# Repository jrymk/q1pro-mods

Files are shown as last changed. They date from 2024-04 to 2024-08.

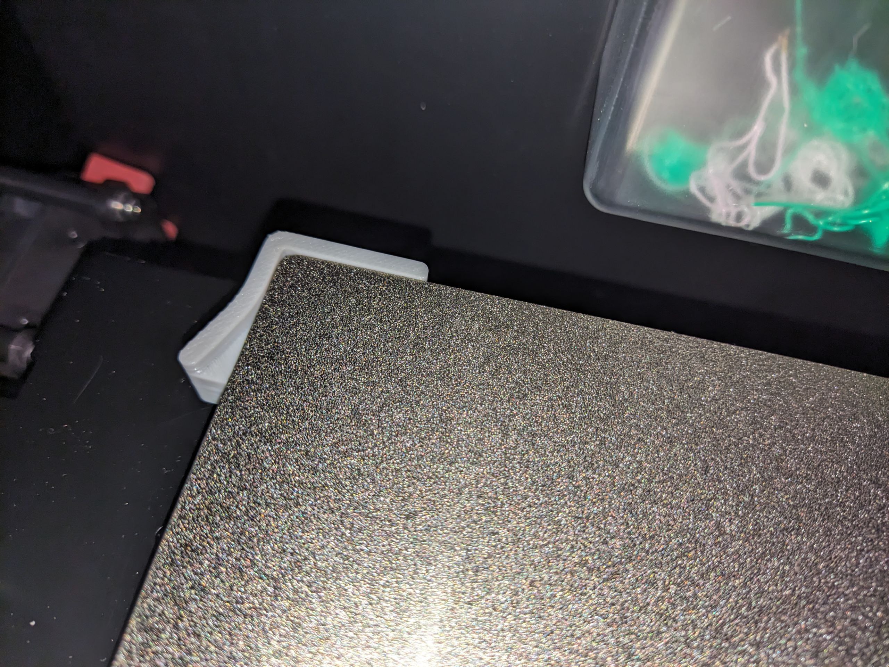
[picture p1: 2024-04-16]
Build Plate Guide/MakerWorld/photo_1_2024-04-17_00-07-08.jpg

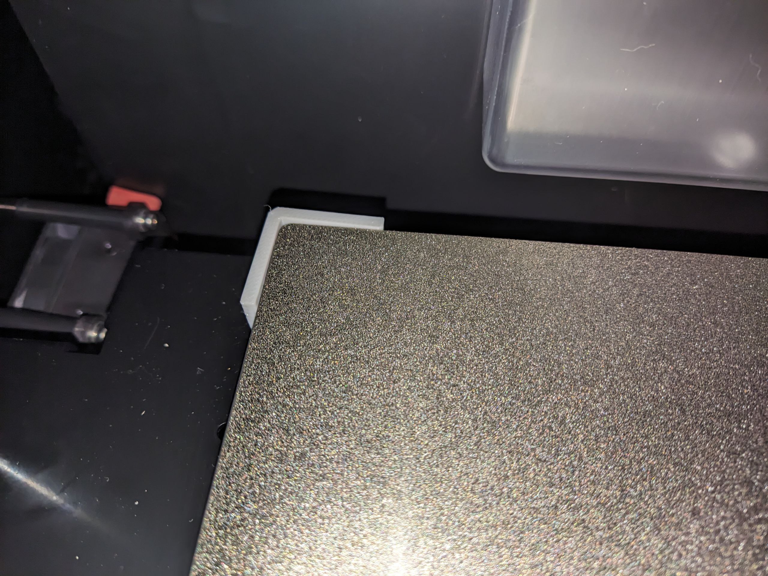
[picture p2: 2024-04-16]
Build Plate Guide/MakerWorld/photo_2024-04-17_00-09-56.jpg

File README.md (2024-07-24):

# Qidi Q1 Pro Mods
configuration and hardware modifications for the Qidi Q1 Pro 3D printer

Star and watch this repo for updates.

| Mods | Description |
| --- | --- |
| [printer.cfg](https://github.com/jrymk/q1pro-mods/tree/main/config) | Temperature sensors and minor tweaks |
| [gcode_macro.cfg](https://github.com/jrymk/q1pro-mods/tree/main/config) | Organized macros, revamped Z offset, optimized nozzle cleaning and smoother purge bucket operation, useful macros, etc. |
| [fluidd update](https://github.com/jrymk/q1pro-mods/blob/main/fluidd-update.md) | This is work from Reddit user [u/billkenney](https://www.reddit.com/user/billkenney/) on [r/QIDI](https://www.reddit.com/r/QIDI/comments/1buinmx/the_last_working_version_of_fluidd/). Click the link on the left for installation guide.
| [Build Plate Guide](https://makerworld.com/en/models/429171#profileId-333494) | _Revision 2 only!_ Replace stock bed shroud with split build plate guide for better bed flatness |
| [Ugly Spool Holder](https://makerworld.com/en/models/431964#profileId-336548) | _Revision 2 recommended._ Voron style spool holder, printed in one piece in a relatively strong orientation |

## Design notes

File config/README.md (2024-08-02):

# Modified configs for the Qidi Q1 Pro

**Use at your own risk.**\
You actually need to place the steel build plate on the bed when it homes and probes. The aluminum bed will NOT trigger the inductive probe. Increase the Z offset way high if you're scared of damaging the build plate.

If you unplug your printer, you might need to reinstall these config files / rename files to "unbackup" the files we modified

## Quick start TL;DR for advanced Klipper users
- `printer.cfg`: Replace everything except the SAVE_CONFIGS
- `gcode_macro.cfg`: Replace everything
- Start a print (with `PRINT_START HOTEND= BED= CHAMBER=`) (or call `GET_ZOFFSET` and use a paper or feeler guage) and adjust Z offset
- Issue `Z_OFFSET_APPLY_PROBE` to apply the Z offset. Z offset is cleared in subsequent `PRINT_START`
- Issue `Z_OFFSET_APPLY_ENDSTOP` to set endstop position, which affects where the nozzle sits relative to the bed before Z calibration

## Full Installation and First Use Guide
Please read it all before you start performing on your printer.

1. Back up the `gcode_macro.cfg` file, or just simply rename it.\
\
The `printer.cfg` file is automatically backed up by the system. You can download it or copy it to be extra safe.
2. Update the `printer.cfg` file. Select everything before `#*# <-- SAVE_CONFIG -->` and replace it with the file in this repo
    - Copy the contents of [printer.cfg](https://github.com/jrymk/q1pro-mods/blob/main/config/printer.cfg)\
    
    - Select as shown below and paste\
    
    - Save\
    
3. Create the new `gcode_macro.cfg` file
    - Add a new file and name it `gcode_macro.cfg`\
    
    
    - Copy the contents of [gcode_macros.cfg](https://github.com/jrymk/q1pro-mods/blob/main/config/gcode_macro.cfg) file\
    
    - Open the newly created file in the printer web interface and paste it in\
    
    - Save and Restart\
    
4. In theory, you may now send a print job. If you don't feel safe, set the Z offset way high, say 1mm, with the following command:
    ```
    SET_GCODE_OFFSET Z=1 MOVE=1
    ```
    after a print job with a large first layer area is sent. And you may use the printer display or the web interface to adjust the nozzle closer by using the "UP" arrow. If it is way high (which it should), you can use the same command with a smaller number to speed up the process, like `SET_GCODE_OFFSET Z=0.2 MOVE=1`.\
    
5. Also check if the nozzle cleaning works well on your printer and filament. **Check if the nozzle tip is clean**, and filament does not ooze during probing. If it does, drop the probing temperature, as shown below. This value is set high as the author does not print PLA at all, and this reduces the cooldown time before probing. Even if it doesn't ooze, try not to set it above 180 degrees as it may damage the build surface.
   Be extra sure that the nozzle looks nice and clean when calibrating your nozzle offset. If the nozzle is not clean during a print setup is fine, as the first layer will just be too high. But if you adjust the Z offset and save this result to the nozzle offset, subsequent prints will be too low, and **may damage your build plate!**\
    
6. After dialing the first layer, you may leave it printing, or cancel it. Type in `Z_OFFSET_APPLY_PROBE` to apply the adjustments you made with the Z offset to the nozzle probe, so the next time it will be perfect. By default, the Z offset you made are cleared when the next print job starts, so make sure to save it by issuing this command right now.
7. After that, you can also issue `Z_OFFSET_APPLY_ENDSTOP`, so the nozzle offset is about right even before any nozzle probing occurs. Still, try not to drive the bed near Z=0 before a print.
   ```
   Z_OFFSET_APPLY_PROBE
   Z_OFFSET_APPLY_ENDSTOP
   ```
   By default, the Z axis can go 1mm negative, to account for homing and probing variances. After you dial the endstop and nozzle offsets from my default "safe-ish" values, you may increase this number (to say -0.5mm or -0.2mm) to prevent disasters from happening. The -1 setting should prevent your bed and nozzles from permanently bending out of shape, since the bed is on springs, but you may further increase it to also save your build plate.
8. You may issue the `GET_ZOFFSET` command when the nozzle is clean to take a measurement of the endstop offset compared to the result from the last G28 home, without starting a print. And you can adjust the nozzle height with a piece of paper or a feeler guage and the Z offset controls to calibrate the nozzle height this way.

## Features
### Revamped Auto Z Offset
`Z_OFFSET_APPLY_ENDSTOP` (apply nozzle offset to endstop) updates the endstop position instead of the fixed -0.2 for the default Qidi config for an inductive, which makes no sense. It also requires `position_min: -4`, which may lead to a disaster.\


`Z_OFFSET_APPLY_PROBE` (apply babystep z offset to nozzle offset) updates the nozzle offset after a print finishes, applying the babystepping done during the print. This should not be done frequently, but when you do, it is easy to keep the results. The piezo sensors on the bed do not perfectly triggers when the nozzle contacts, probably due to flexes in the bed, insensitivity in the threshold circuitry, or some delay. Regardless, this value seems to be fairly consistent. This value is usually between 0.05mm and 0.1mm. To keep it safe, it will be at 0.1 by default. You may decrease the Z offset (using the up arrow) during a print to fine adjust it. Make sure the nozzle is clean during the nozzle probing, at least when first using these modified config files. Any positive value here should be all "safe", if the offset of the trigger point of the nozzle probe on your machine (usually less than 0.1mm) is less than your first layer Z height (usually greater than 0.1mm), then the nozzle will not dig into the build plate, ruining it. \
\


There is also an option to always apply the babystep offset to the nozzle. See more in `gcode_macros.cfg` `[gcode_macro JRYMK_MOD_VARIABLES]` `variable_keep_babystep_adjustments: 0/1`.

`GET_ZOFFSET` conditionally calibrates the bed sensor, probes with a nozzle, and will set the kinematic Z=0 position to the true zero. The probing position is randomized to prevent wear on the build plate, because although we are probing at a reduced nozzle temperature, I can still see wear marks on the bed from the default Qidi's configs with the fixed probing location.

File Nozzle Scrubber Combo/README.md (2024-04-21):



And no, it doesn't work well. I'll probably redesign the whole lever system, or add support braces to the existing arm.

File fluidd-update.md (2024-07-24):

# Update fluidd to v1.28.1
Source Reddit post: [The last working version of Fluidd at r/QIDI](https://www.reddit.com/r/QIDI/comments/1buinmx/the_last_working_version_of_fluidd/) by [u/billkenney](https://www.reddit.com/user/billkenney/)



Finally working ETA estimation, stepper temperatures, Z offset apply options, diagnostics feature, and A TON more! This is probably the most useful mod in this repo tbh, thanks billkenney!

## Installation
1. Download the fluidd archive file from the Google Drive link in this post: [Reddit](https://www.reddit.com/r/QIDI/comments/1buinmx/the_last_working_version_of_fluidd/)
2. Upload the fluidd file to the printer. The easiest way is to upload via the web interface:


3. Use Terminal with PowerShell or any other ssh client, log in to the printer.

```
ssh root@192.168.x.x
```
If it asks for the fingerprint stuff, type in `yes`.\
The password is `makerbase`.

4. Back up the fluidd folder, let's copy it to the root home directory. It doesn't _really_ matter, nothing is gonna go wrong, right?
```
cd /home/mks
sudo cp -r fluidd ~/fluidd-bak
```
5. Copy the uploaded fluidd-1.28.tgz to the home directory.
```
cp klipper_config/fluidd-1.28.tgz fluidd.tgz
```
6. Delete the existing fluidd folder
```
rm -rf fluidd
```
7. Unpack fluidd.tgz
```
tar -xzf fluidd.tgz
```
8. Maybe reboot, maybe restart services. I didn't, and it worked fine.

## Notes
- Z controls are now inverted

The arrows for toolhead control used to indicate bed movement by default, but now up means Z+ (bed down) and down means Z- (bed up).
The Z offset adjustment controls don't seem to apply, so you'll get up for Z+ and down for Z- regardless.
Be careful! Don't go the wrong way...

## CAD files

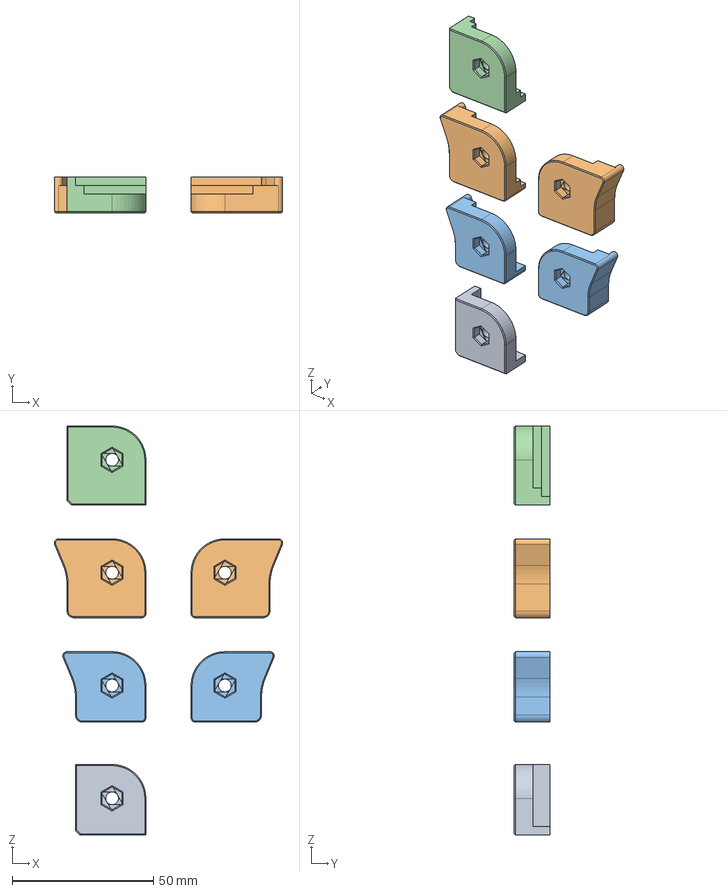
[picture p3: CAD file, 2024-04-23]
Build Plate Guide/CAD/Bed Build Plate Alignment Stops v6.step
81.0 x 12.6 x 145.0 mm
Bed Build Plate Alignment Stops_1
v2 250
v2 256
v1 256

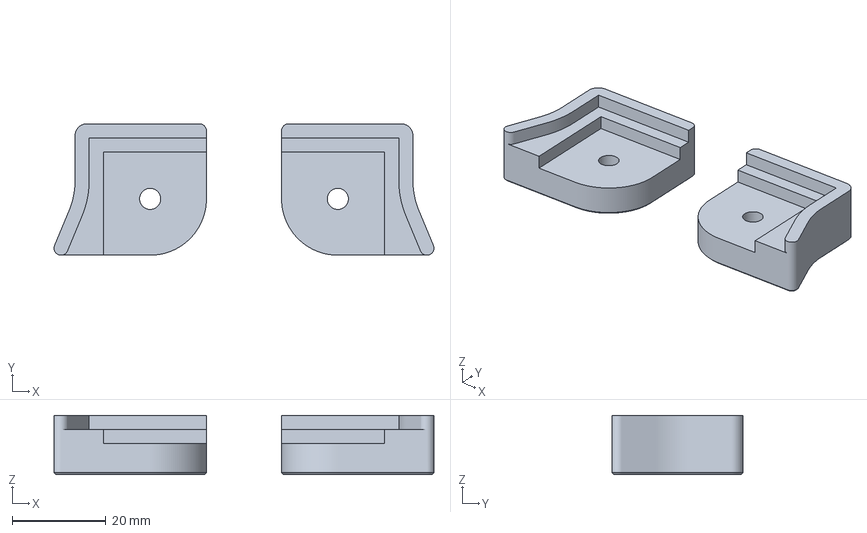
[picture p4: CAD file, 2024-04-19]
Build Plate Guide/MakerWorld/makerworld [v2 256].3mf
81.0 x 28.0 x 12.6 mm

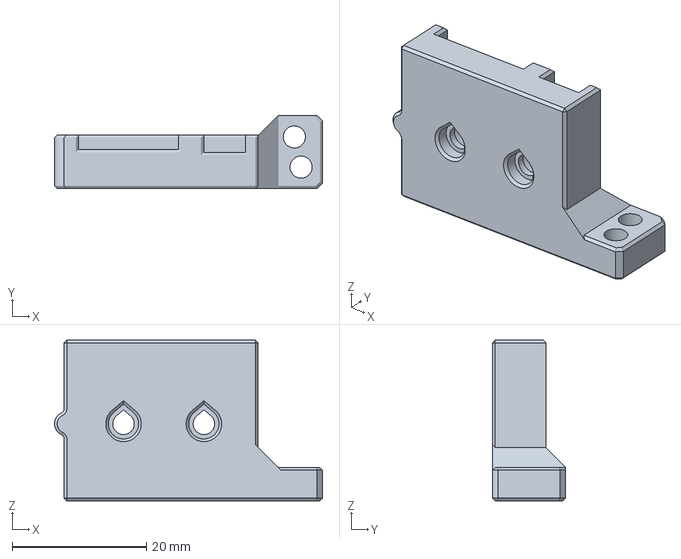
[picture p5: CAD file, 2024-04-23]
Nozzle Scrubber Combo/Bambu Nozzle Wiper v2.3mf
40.0 x 10.9 x 24.0 mm

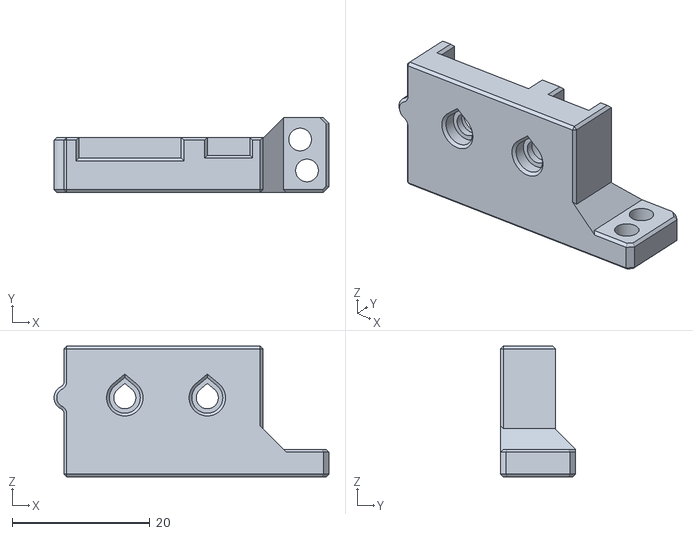
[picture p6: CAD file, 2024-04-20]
Nozzle Scrubber Combo/STLs/v1.stl
40.0 x 10.9 x 19.0

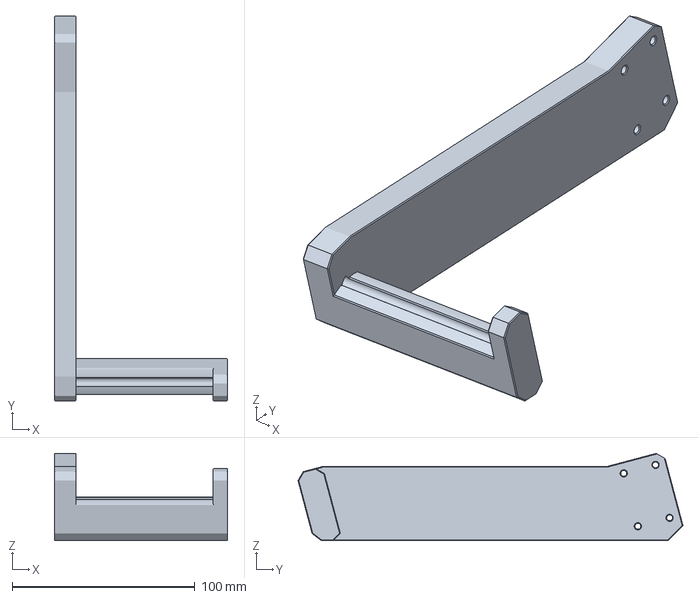
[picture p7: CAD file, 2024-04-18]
Ugly Spool Holder/MakerWorld/Ugly Spool Holder.3mf
95.0 x 210.9 x 47.8 mm

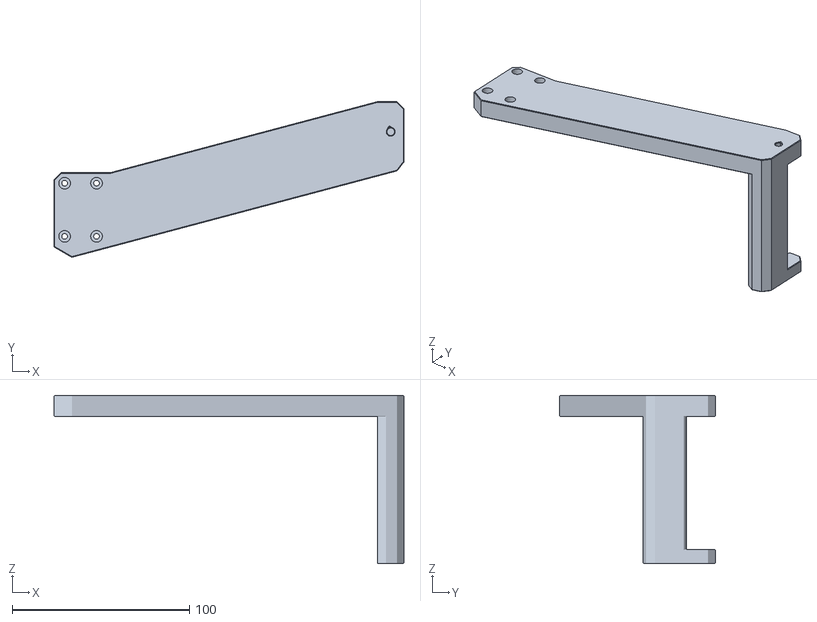
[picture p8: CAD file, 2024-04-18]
Ugly Spool Holder/STLs/Ugly Spool Holder.stl
197.5 x 87.8 x 95.0

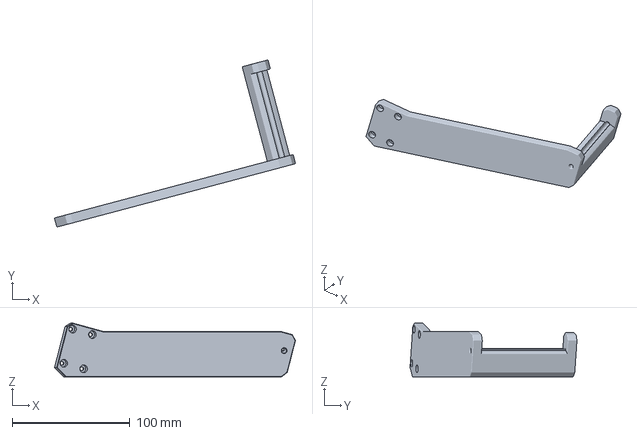
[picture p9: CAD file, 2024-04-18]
Ugly Spool Holder/Ugly Spool Holder (Qidi Slicer).3mf
204.3 x 141.5 x 45.6 mm

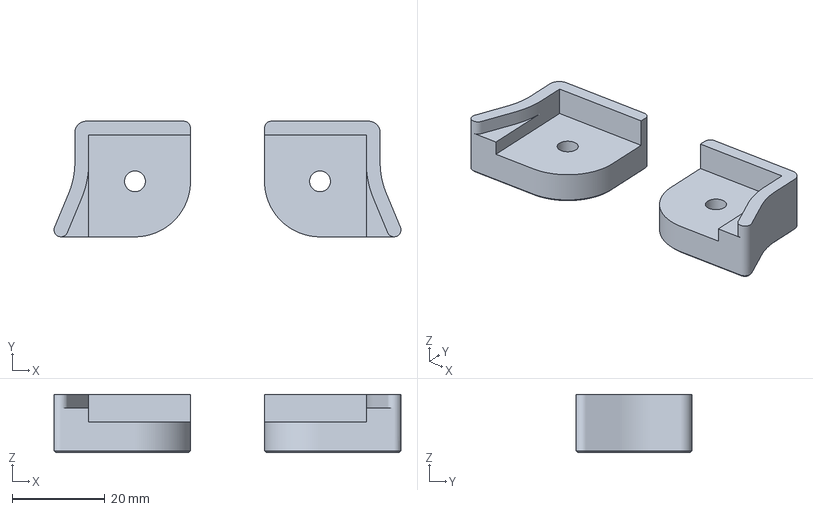
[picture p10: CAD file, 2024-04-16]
Build Plate Guide/MakerWorld/makerworld.3mf
75.0 x 25.0 x 12.6 mm

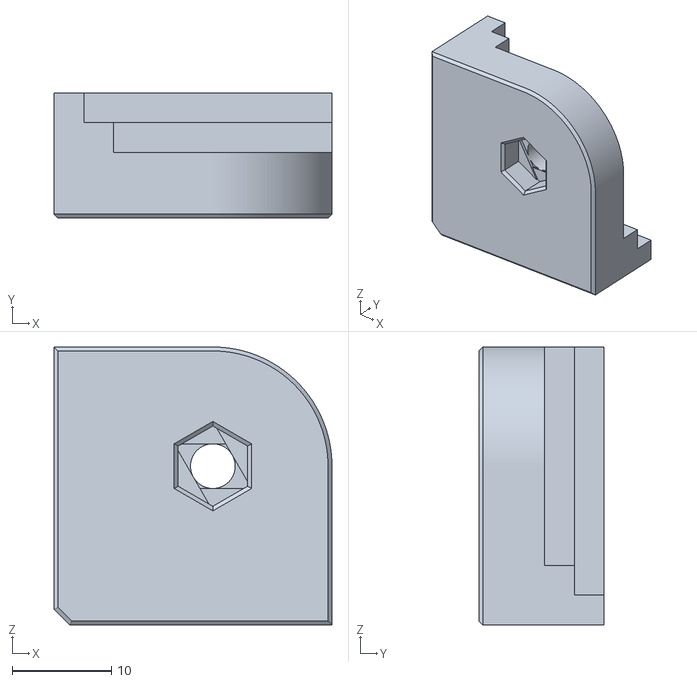
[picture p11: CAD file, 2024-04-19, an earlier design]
Build Plate Guide/STLs/Bed Build Plate Alignment Stops v1 [Bambu 256].stl
28.0 x 12.6 x 28.0

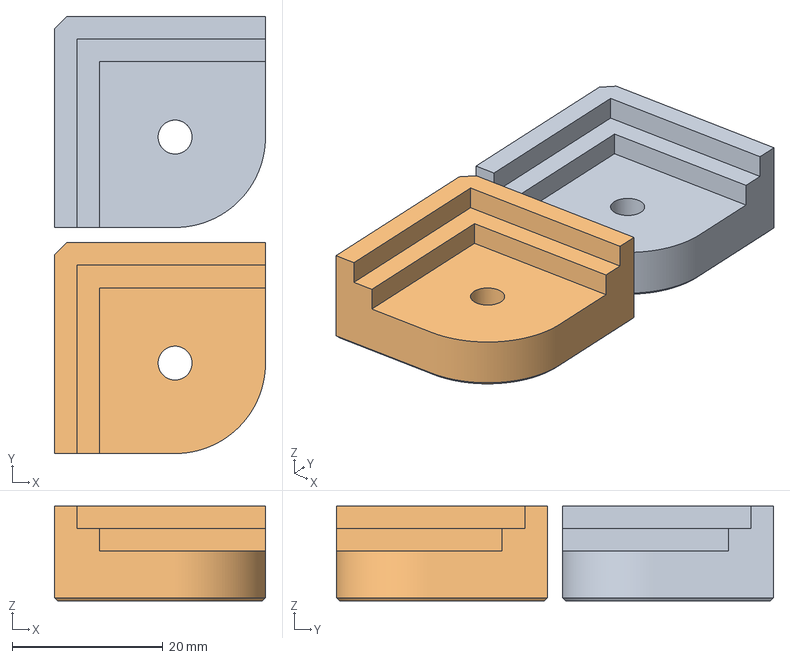
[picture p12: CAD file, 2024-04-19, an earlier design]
Build Plate Guide/MakerWorld/makerworld [v1 256].3mf
28.0 x 58.0 x 12.6 mm
Bed Build Plate Alignment Stops v1 [Bambu 256].stl x 2

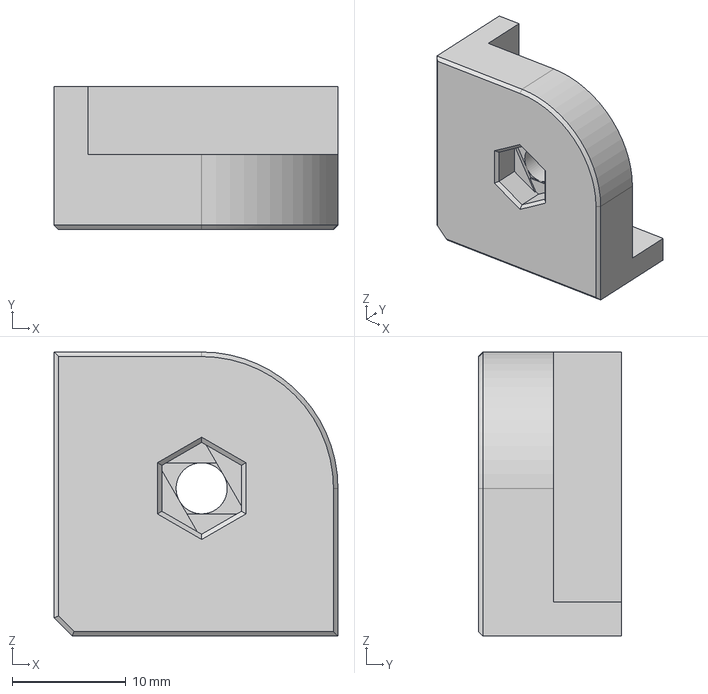
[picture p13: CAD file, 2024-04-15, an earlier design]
Build Plate Guide/CAD/Bed Build Plate Alignment Stops v1.step
25.0 x 12.6 x 25.0 mm

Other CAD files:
Build Plate Guide/STLs/Bed Build Plate Alignment Stops v2 [Bambu 256].stl
Build Plate Guide/STLs/Bed Build Plate Alignment Stops v1 (Qidi Slicer).3mf
Build Plate Guide/CAD/Bed Build Plate Alignment Stops v2.step
Build Plate Guide/CAD/Bed Build Plate Alignment Stops v1.f3d
Build Plate Guide/CAD/Bed Build Plate Alignment Stops v2.f3d
Build Plate Guide/CAD/Bed Build Plate Alignment Stops v5.f3z
Build Plate Guide/STLs/Bed Build Plate Alignment Stops v1.stl
Build Plate Guide/STLs/Bed Build Plate Alignment Stops v2.stl
Nozzle Scrubber Combo/STLs/Bambu Nozzle Wiper v2.stl

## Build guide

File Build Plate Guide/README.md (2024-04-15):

# Improved Build Plate Alignment Guide

Docs available at https://makerworld.com/en/models/429171#profileId-333494

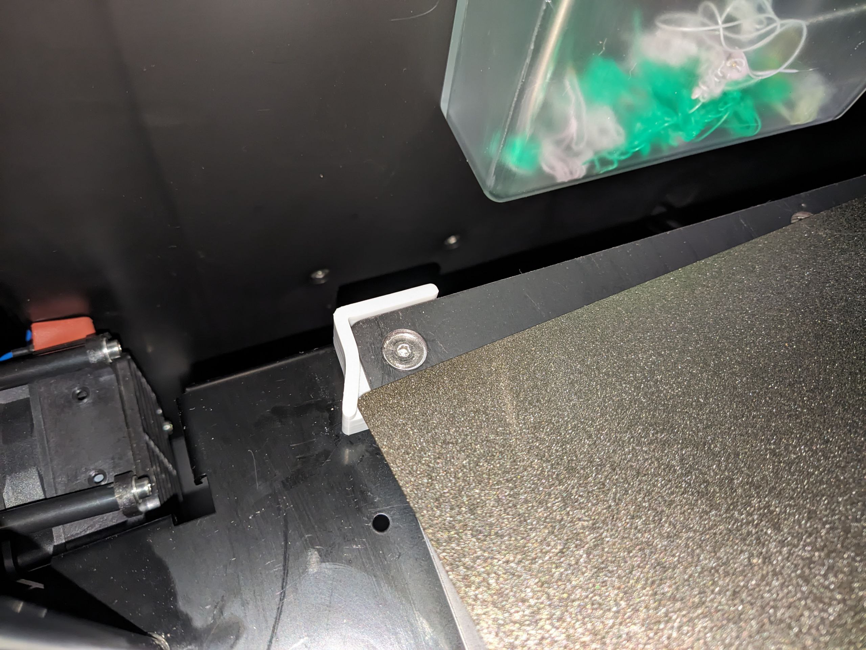
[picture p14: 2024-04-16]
Build Plate Guide/MakerWorld/photo_2_2024-04-17_00-07-08.jpg

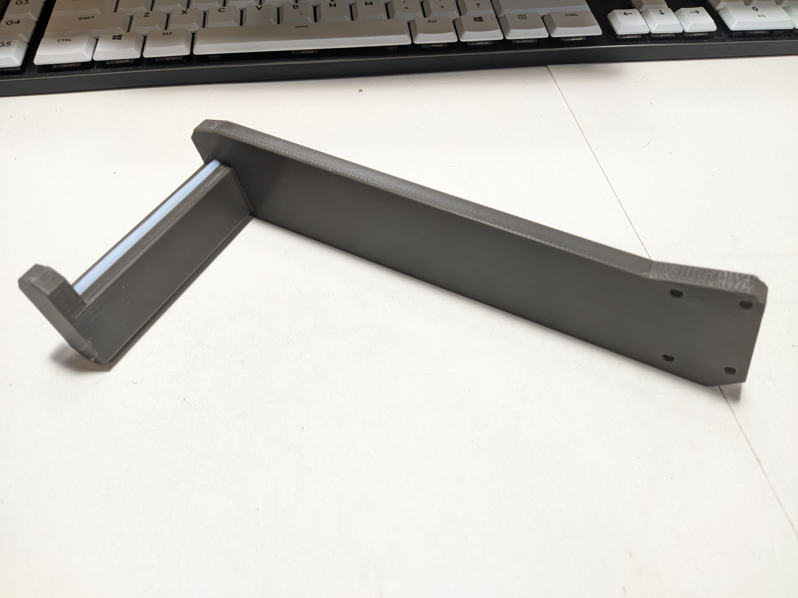
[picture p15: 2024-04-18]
Ugly Spool Holder/MakerWorld/photo_2_2024-04-17_17-56-13.jpg

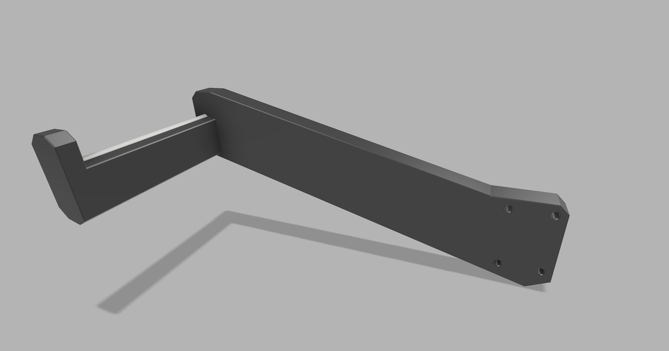
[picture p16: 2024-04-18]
Ugly Spool Holder/MakerWorld/render.png

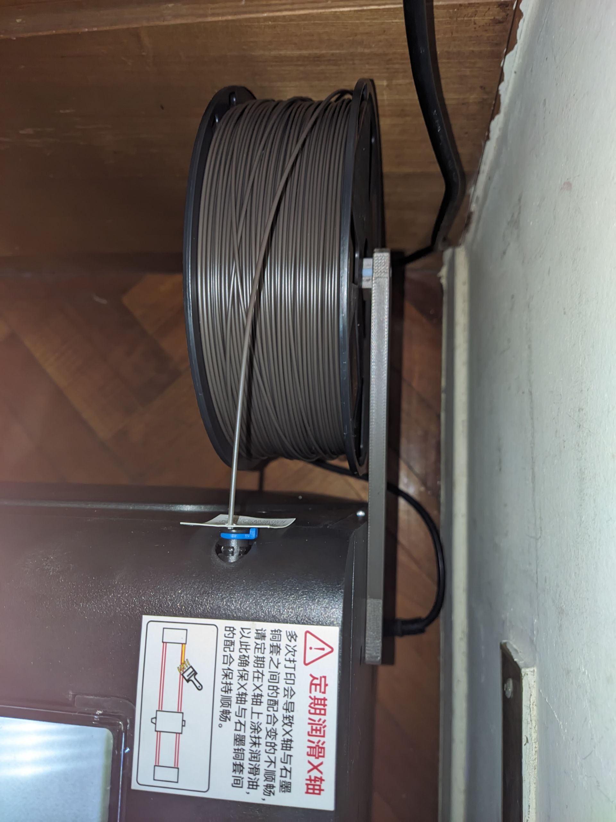
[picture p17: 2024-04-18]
Ugly Spool Holder/MakerWorld/photo_2024-04-17_17-42-42.jpg

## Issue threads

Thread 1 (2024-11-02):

Error: Option 'position_endstop' in section 'stepper_z' must be specified.

tralamazza, 2024-11-02:
Effect: Printer is halted.

The original file has a value `position_endstop:-0.2`, while the provided config has this commented out `#position_endstop: 2.600`.

jrymk, 2024-11-02:
It is likely because I have used the Z_OFFSET_APPLY_ENDSTOP to set the origin for the inductive sensor for preliminary homing, and it has updated the save config section, causing the entries on the top to be commented out. I try to make it more inline with the actual value. For your information, my actual trigger point for the inductive probe is like so:
```
#*# [stepper_z]
#*# position_endstop = 2.519
```
Qidi setting it to -0.2 means that when you manually jog to Z=0, the nozzle would be over 2mm from the bed. This does prevent some accidents from happening, and it should only update to the appropriate value after the get_zoffset procedure. But this isn't technically correct, so I have omitted their implementation.

You may simply uncomment the line, perform GET_ZOFFSET, and then Z_OFFSET_APPLY_ENDSTOP to make the endstop position reflect the actual probe trigger point.

tralamazza, 2024-11-02:
Thank you for the detailed answer. I will take some time to fully understand the implications.

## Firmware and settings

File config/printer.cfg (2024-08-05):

# Q1_Pro
# V4.4.14 2024-3-14 
# update: heater_generic hot -> chamber
#         out_put_pin fan0 -> fan_generic cooling_fan
#         out_put_pin fan2 -> fan_generic auxiliary_cooling_fan
#         out_put_pin fan3 -> fan_generic chamber_circulation_fan
#         heater_fan hot -> heater_fan chamber
#         verify_heater hot -> verify_heater chamber
# V4.4.17 2024-3-29
# update: delete comments
#         add time_update macro
#         [bed_mesh] 6,6 ->8,8
# V4.4.18mod 2024-4-14
# modify: add temperature monitor
#         change electronics bay cooling fan config
#         increase bed mesh precision
# V4.4.19 2024-4-16
# update: add [chamber_fan chamber_fan]
# V4.4.20 2024-6-17
# update: [smart_effector] 
#           samples_result: average -> submaxmin
#           speed: 10 -> 5
#           sample_retract_dist: 3.0 -> 5.0
#         [stepper_x]
#           position_max: 245 -> 246
# V4.4.20mod 2024-7-9

[include timelapse.cfg]
[include Adaptive_Mesh.cfg]
[include gcode_macro.cfg]
[include plr.cfg]
[include time_update.cfg]

[mcu]
serial: /dev/ttyS2
restart_method: command

[mcu U_1]
serial: /dev/ttyS0
restart_method: command

[respond]
default_type: echo

[save_variables] 
filename =/home/mks/klipper_config/saved_variables.cfg

[resonance_tester]
accel_per_hz: 150
max_smoothing:0.5

[duplicate_pin_override]
pins:
     gpio21 ,U_1:PC3

[bed_screws]
screw1:10,10
screw1_name: Front left
screw2: 230,10
screw2_name: Front right
screw3: 125,240
screw3_name: Last right

[screws_tilt_adjust] 
screw1:-5,5.6
screw1_name: Front left
screw2: 216,5.6
screw2_name: Front right
screw3: 103,235.6
screw3_name: Last right
screw_thread: CW-M4

[force_move]
enable_force_move : false

[hall_filament_width_sensor]
adc1: gpio27
adc2: gpio28
cal_dia1: 1.48 # calibration data from author's unit
cal_dia2: 1.97 # this hall effect filament sensor is kinda useless as width sensor actually,
raw_dia1: 13422 # because the inlet is not mounted rigidly, the filament will pivot and make the reading really high when bend to the left
raw_dia2: 14765 
default_nominal_filament_diameter: 1.75
max_difference: 0
measurement_delay: 102
enable: false
measurement_interval: 10
logging: False
min_diameter: 0.9
use_current_dia_while_delay: False
pause_on_runout: True
runout_gcode:
            pause
            RESET_FILAMENT_WIDTH_SENSOR
            M118 Filament run out
event_delay: 3.0
pause_delay: 0.5

[extruder]
step_pin:gpio5
dir_pin:gpio4
enable_pin:!gpio10
rotation_distance: 53.7  #22.6789511	#Bondtech 5mm Drive Gears
gear_ratio: 1517:170
microsteps: 16
full_steps_per_rotation: 200	#200 for 1.8 degree, 400 for 0.9 degree
nozzle_diameter: 0.400
filament_diameter: 1.75
min_temp: 0
max_temp: 360
min_extrude_temp: 175
smooth_time: 0.000001
heater_pin:gpio24
sensor_type:MAX6675
sensor_pin:gpio17
spi_speed: 100000
spi_software_sclk_pin:gpio18
spi_software_mosi_pin:gpio19
spi_software_miso_pin:gpio16
max_power: 1
pressure_advance: 0.032
pressure_advance_smooth_time: 0.03
max_extrude_cross_section:500
instantaneous_corner_velocity: 10.000
max_extrude_only_distance: 1000.0
max_extrude_only_velocity:5000
max_extrude_only_accel:2000
step_pulse_duration:0.000002
control = pid  # default values from the author's unit
pid_kp = 44.527
pid_ki = 10.994
pid_kd = 45.084

[tmc2209 extruder]
uart_pin:gpio6
interpolate: True
run_current: 0.714
stealthchop_threshold: 0

[adxl345]
cs_pin:gpio13
spi_software_sclk_pin:gpio14
spi_software_mosi_pin:gpio15
spi_software_miso_pin:gpio12
axes_map: -x, z, -y
# WTF? (probably remanence from Qidi testing [FR] Use accelerometer as Z probe and then just left it there...
probe_pin: gpio9
int_pin: int1
tap_thresh: 3500
tap_dur: 0.01
z_offset: -0.1

[printer]
kinematics:corexy
max_velocity: 600
max_accel: 20000
max_accel_to_decel: 10000
max_z_velocity: 10
max_z_accel: 1000
square_corner_velocity: 8

[stepper_x]
step_pin:U_1:PB4
dir_pin:!U_1:PB3
enable_pin:!U_1:PB5
microsteps:32
rotation_distance: 39.88
full_steps_per_rotation:200
endstop_pin:tmc2240_stepper_x:virtual_endstop
position_min: -5.5  
position_endstop: -5.5
position_max:245
homing_speed:50
homing_retract_dist:0
homing_positive_dir:False
step_pulse_duration:0.0000001

[stepper_y]
step_pin:U_1:PC14
dir_pin:!U_1:PC13
enable_pin:!U_1:PC15
microsteps: 32
rotation_distance: 39.88
full_steps_per_rotation:200
endstop_pin:tmc2240_stepper_y:virtual_endstop
position_min: -4.5  
position_endstop: -4.5
position_max: 258
homing_speed:50
homing_retract_dist:0
homing_positive_dir:False
step_pulse_duration:0.0000001

[stepper_z]
step_pin:U_1:PC10
dir_pin:U_1:PA15
enable_pin:!U_1:PC11
microsteps: 128
rotation_distance: 4
full_steps_per_rotation: 200
endstop_pin:probe:z_virtual_endstop #U_1:PC3 for Z-max
endstop_pin_reverse:tmc2209_stepper_z:virtual_endstop
#position_endstop: 2.600
position_endstop_reverse:248
position_max:248
position_min: -0.5
homing_speed: 5
homing_speed_reverse: 10
second_homing_speed: 5
homing_retract_dist: 4.0
homing_positive_dir:false
homing_positive_dir_reverse:true
step_pulse_duration:0.0000001

[stepper_z1]
step_pin:U_1:PB1
dir_pin:U_1:PB6
enable_pin:!U_1:PB0
microsteps: 128
rotation_distance: 4
full_steps_per_rotation: 200
step_pulse_duration:0.0000001
endstop_pin_reverse:tmc2209_stepper_z1:virtual_endstop

[z_tilt]
z_positions:
    -59,125
    307.5,125

points:
    0,125
    215,125

speed: 500
horizontal_move_z: 5
retries: 2
retry_tolerance: 0.05

[tmc2240 stepper_y]
cs_pin:U_1:PB9
spi_software_sclk_pin:U_1:PA5
spi_software_mosi_pin:U_1:PA7
spi_software_miso_pin:U_1:PA6
spi_speed:200000
run_current: 1.07
#hold_current: 0.5
interpolate: False
stealthchop_threshold:0
diag0_pin:!U_1:PC0
driver_SGT:1

[tmc2240 stepper_x]
cs_pin:U_1:PD2
spi_software_sclk_pin:U_1:PA5
spi_software_mosi_pin:U_1:PA7
spi_software_miso_pin:U_1:PA6
spi_speed:200000
run_current: 1.07
#hold_current: 0.5
interpolate: False
stealthchop_threshold:0
diag0_pin:!U_1:PB8
driver_SGT:1

[tmc2209 stepper_z]
uart_pin:U_1: PC5
run_current: 0.6
#hold_current: 0.17
interpolate: False
stealthchop_threshold: 9999999999
diag_pin:^U_1:PC12
driver_SGTHRS:130

[tmc2209 stepper_z1]
uart_pin:U_1: PB7
run_current: 0.6
#hold_current: 0.17
interpolate: False
stealthchop_threshold: 9999999999
diag_pin:^U_1:PA13
driver_SGTHRS:130

[heater_bed]
heater_pin: U_1:PB10
sensor_type:NTC 100K MGB18-104F39050L32
sensor_pin:U_1: PA0
max_power: 1.0
control = pid  # default values from the author's unit
pid_kp = 73.391
pid_ki = 1.519
pid_kd = 886.192
min_temp: -60
max_temp: 125

[heater_generic chamber]
heater_pin:U_1:PC8
max_power:1.0
sensor_type:NTC 100K MGB18-104F39050L32
sensor_pin:U_1:PA1
control = pid  # default values from the author's unit
pid_kp = 70.648
pid_ki = 0.298
pid_kd = 4193.821
min_temp:-100
max_temp:75
pwm_cycle_time: 0.1 # in case it does weird things to the SSR

[verify_heater chamber]
max_error: 300
check_gain_time:480
hysteresis: 5
heating_gain: 1

[verify_heater extruder]
max_error: 120
check_gain_time:20
hysteresis: 5
heating_gain: 1

[verify_heater heater_bed]
max_error: 200
check_gain_time:60
hysteresis: 5
heating_gain: 1

[fan_generic auxiliary_cooling_fan]
pin: U_1:PA8
shutdown_speed: 0.0
cycle_time: 0.0100
hardware_pwm: false
kick_start_time: 0.100
off_below: 0.0

[fan_generic chamber_circulation_fan]
pin:U_1:PC9
shutdown_speed: 0.0
cycle_time: 0.100
hardware_pwm: false
kick_start_time: 0.100
off_below: 0.0

[chamber_fan chamber_fan]
pin:U_1:PA4
max_power: 1.0
shutdown_speed: 0
kick_start_time: 0.5
heater:chamber
fan_speed: 1.0
off_below: 0
idle_timeout:60
idle_speed:1.0

[heater_fan hotend_fan]
pin:gpio25
max_power: 1.0
shutdown_speed:1.0
kick_start_time: 0.5
heater: extruder
heater_temp: 50.0
fan_speed: 1.0
off_below: 0

[heater_fan hotend_fan2]
pin:gpio11
max_power: 1.0
shutdown_speed:1.0
kick_start_time: 0.5
heater: extruder
heater_temp: 50.0
fan_speed: 1.0
off_below: 0

[fan_generic cooling_fan]
pin:gpio2
max_power: 1.0
shutdown_speed: 0
cycle_time: 0.0100
hardware_pwm: false
kick_start_time: 0.100
off_below: 0.0

[temperature_sensor host]
sensor_type: temperature_host

[temperature_sensor toolhead_board_mcu]
sensor_type: temperature_mcu

[temperature_sensor mainboard_mcu]
sensor_type: temperature_mcu
sensor_mcu: U_1

[fan_generic board_fan]
pin:U_1:PC4
max_power:1.0
shutdown_speed:1.0
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

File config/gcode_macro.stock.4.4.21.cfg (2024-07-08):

# Q1_Pro
# V4.4.16 2024-3-14
# update: variable change M106 & M141 & M107
# V4.4.16 2024-3-26
# update: variable change [homing_override]->add M204 S10000
# V4.4.20 2024-6-17
# update: Z_DOUDONG CLEAR_NOZZLE get_zoffset rewrite
#         move_subzoffset added 
# V4.4.21 2024-6-22
# update: Enable chamber exhaust fan by default when chamber temp not set

[gcode_macro test_zoffset]
gcode:
    G28
    get_zoffset
    G1 X{120 - printer.probe["x_offset"]} Y{120 - printer.probe["y_offset"]} F9000
    G1 Z10 F600
    probe
    M400
    G4 P5000
    G1 Z10 F600

[gcode_macro move_subzoffset]
gcode:
     
    G1 Z{printer.probe.last_z_result} F600

[gcode_macro get_zoffset]
gcode:
    G1 Z10 F600
    Z_DOUDONG
    ;G4 P500
    QIDI_PROBE_PIN_1
    M204 S30
    G4 P500
    probe probe_speed=5 lift_speed=5 samples=5 sample_retract_dist=5
    move_subzoffset
    M114
    SET_KINEMATIC_POSITION Z=-0.07
    G1 Z30 F600
    QIDI_PROBE_PIN_2
    M204 S10000

[gcode_macro save_zoffset]
gcode:
    {% if printer.gcode_move.homing_origin.z < 0.5 %}
       SAVE_VARIABLE VARIABLE=z_offset VALUE={printer.gcode_move.homing_origin.z}
    {% endif %}

[gcode_macro set_zoffset]        
gcode:
    {% set z = printer.save_variables.variables.z_offset %}
    SET_GCODE_OFFSET Z={z} MOVE=0

[gcode_macro CLEAR_NOZZLE_PLR]
gcode:
    {% set hotendtemp = params.HOTEND|default(250)|int %}
    {% if (printer.gcode_move.position.z ) < 35 %}
        G90
        G1 Z35 F900
    {% else %}
        G91
        G1 Z5 F900 
        G90
    {% endif %}
    G1 X97 F15000
    G1 Y243 F15000
    G1 Y254 F800

    M109 S{hotendtemp}

    G92 E0
    G1 E80 F400
    M106 S255

    G1 X97 F500
    G1 X85 F2000
    G1 X97 F2000
    G1 X85 F2000
    G1 X97 F2000
    G1 X85 F2000
    G1 X97 F2000
    G1 X85 F2000
    G1 X97 F2000
    G1 X85 F2000
    G1 X97 F2000
    G1 X85 F2000
    G1 X97 F2000
    G1 Y240 F800

[gcode_macro CLEAR_NOZZLE]
gcode:
    {% set hotendtemp = params.HOTEND|int %}
    {% if (printer.gcode_move.position.z ) < 35 %}
        G1 Z35 F900
    {% else %}
        G91
        G1 Z5 F900 
        G90
    {% endif %}
    G1 X97 F15000
    G1 Y243 F15000
    G1 Y254 F800

    M109 S{hotendtemp}

    G92 E0
    G1 E80 F400
    M106 S255
    M400
    M106 P2 S0
    M104 S0
    TEMPERATURE_WAIT SENSOR=extruder MAXIMUM={hotendtemp-20}

    G1 X85 F2000
    G1 X97 F2000
    G1 X85 F2000
    G1 X97 F2000
    G1 X85 F2000
    G1 X97 F2000
    G1 X85 F2000
    G1 X97 F2000
    G1 X85 F2000

    G1 X65 F500
    G1 X88 F500
    G1 X65 F500
    G1 X88 F500
    G1 X65 F500
    G1 X88 F500
    G1 X65 F500
    G1 X88 F500
    G1 X65 F500 
    G1 X97 F500
    
    G1 X85 F2000
    G1 X97 F2000
    G1 X85 F2000
    G1 X97 F2000
    G1 X85 F2000
    G1 X97 F2000
    G1 X85 F2000
    G1 X97 F2000
    G1 X85 F2000
    G1 X97 F2000
    
    M400
    M118 Nozzle cleared
    G1 Y240 F800
    G1 Y120 F15000
    G1 X230 F15000
    TEMPERATURE_WAIT SENSOR=extruder MAXIMUM=140
    M107
    M106 P2 S0
    M400
    M118 Nozzle cooled

[gcode_macro PRINT_START]
gcode:
    AUTOTUNE_SHAPERS

    {% set bedtemp = params.BED|int %}
    {% set hotendtemp = params.HOTEND|int %}
    {% set chambertemp = params.CHAMBER|default(0)|int %}
    set_zoffset
    {% if chambertemp == 0 %}
        M106 P3 S255
    {% endif %}
    M104 S0
    M140 S{bedtemp}    
    M141 S{chambertemp}
    G28    
    CLEAR_NOZZLE HOTEND={hotendtemp}

    M190 S{bedtemp}   
#    Z_TILT_ADJUST
    G29
    G0 Z50 F600
    G0 X0 Y0  F6000
    
    M191 S{chambertemp}
    M109 S{hotendtemp}
    M204 S10000

    ENABLE_ALL_SENSOR
    save_last_file

[gcode_macro ENABLE_ALL_SENSOR]
gcode:
    ENABLE_FILAMENT_WIDTH_SENSOR
    RESET_FILAMENT_WIDTH_SENSOR
    query_filament_width
    SET_FILAMENT_SENSOR SENSOR=fila ENABLE=1

[gcode_macro DISABLE_ALL_SENSOR]
gcode:
    SET_FILAMENT_SENSOR SENSOR=fila ENABLE=0
    DISABLE_FILAMENT_WIDTH_SENSOR

[gcode_macro AUTOTUNE_SHAPERS]
variable_autotune_shapers: 'ei'
gcode:

[gcode_macro M84]
rename_existing:M84.1
gcode:
    M84.1
	SET_STEPPER_ENABLE STEPPER=stepper_x enable=0
	SET_STEPPER_ENABLE STEPPER=stepper_y enable=0
	SET_STEPPER_ENABLE STEPPER=stepper_z enable=1
    SET_STEPPER_ENABLE STEPPER=stepper_z1 enable=1
	SET_STEPPER_ENABLE STEPPER=extruder enable=0

[gcode_macro DETECT_INTERRUPTION]
gcode:
    {% set was_interrupted = printer.save_variables.variables.was_interrupted %}
    {% if was_interrupted %}
    M118 Detected unexpected interruption during the last print. Do you want to resume printing? (Do not move the extruder before resuming.)
    M118 Yes: RESUME_INTERRUPTED
    M118 No: CLEAR_LAST_FILE
    {% endif %}
    
[delayed_gcode PRINTER_INIT]
initial_duration:0.2
gcode:
	SET_STEPPER_ENABLE STEPPER=stepper_z enable=1
    SET_STEPPER_ENABLE STEPPER=stepper_z1 enable=1
    BED_MESH_CLEAR      
    SET_FILAMENT_SENSOR SENSOR=fila ENABLE=0

[homing_override]
axes:xyz
gcode: 
    {% set HOME_CUR = 1 %}
    {% set driver_config = printer.configfile.settings['tmc2240 stepper_x'] %}
    {% set RUN_CUR = driver_config.run_current %}
    {% set HOLD_CUR = driver_config.hold_current %}
    M204 S10000
    M220 S100
	{% if params.X is defined %}
	    SET_TMC_CURRENT STEPPER=stepper_x CURRENT={HOME_CUR * 0.7} 
        G28 X
		SET_TMC_CURRENT STEPPER=stepper_x CURRENT={HOME_CUR}     
        BEEP I=1 DUR=100       
        G1 X10 F1200
    {% endif %}

    {% if params.Y is defined %}
		SET_TMC_CURRENT STEPPER=stepper_y CURRENT={HOME_CUR * 0.9} 
		G28 Y
		SET_TMC_CURRENT STEPPER=stepper_y CURRENT={HOME_CUR}  
        BEEP I=1 DUR=100          
       G1 Y10 F1200
    {% endif %}

    {% if params.Z is defined %}
        SET_KINEMATIC_POSITION Z={printer.toolhead.axis_maximum.z-5}
        QIDI_PROBE_PIN_2
        probe samples=2
        SET_KINEMATIC_POSITION Z=1.9
        G1 Z10 F600
        Z_DOUDONG
        QIDI_PROBE_PIN_1
        probe probe_speed=10
        SET_KINEMATIC_POSITION Z=-0.1
        G1 Z30 F480
    {% endif %}

    {% if params.X is undefined %}
    {% if params.Y is undefined %}
    {% if params.Z is undefined %}
        SET_KINEMATIC_POSITION X=0
        SET_KINEMATIC_POSITION Y=0
        SET_KINEMATIC_POSITION Z={printer.toolhead.axis_maximum.z-10}
        G91
        G1 Z7 F600	
        G1 X10 F2400
        G1 Y10 F2400
        G4 P2000
    
       SET_TMC_CURRENT STEPPER=stepper_x CURRENT={HOME_CUR * 0.8} 
        G28 X
    	SET_TMC_CURRENT STEPPER=stepper_x CURRENT={HOME_CUR} 
        BEEP I=1 DUR=100  
        G1 X10 F1200
    
    	SET_TMC_CURRENT STEPPER=stepper_y CURRENT={HOME_CUR * 0.9} 
    	G28 Y
    	SET_TMC_CURRENT STEPPER=stepper_y CURRENT={HOME_CUR} 
        BEEP I=1 DUR=100        
        G1 Y10 F1200

        SET_TMC_CURRENT STEPPER=stepper_x CURRENT={HOME_CUR * 0.8} 
        G28 X
    	SET_TMC_CURRENT STEPPER=stepper_x CURRENT={HOME_CUR} 
        BEEP I=1 DUR=100  
        G1 X10 F1200

        SET_KINEMATIC_POSITION Z={printer.toolhead.axis_maximum.z-10}

        G90
        G1 X120 Y120 F7800
        G91
        QIDI_PROBE_PIN_2
        G28 Z
        G1 Z30  F600
    {% endif %}
    {% endif %}
    {% endif %}
    SET_TMC_CURRENT STEPPER=stepper_x CURRENT={RUN_CUR} 
    SET_TMC_CURRENT STEPPER=stepper_y CURRENT={RUN_CUR} 
    M204 S10000
    G90
    QIDI_PROBE_PIN_2

[gcode_macro SHAPER_CALIBRATE]
rename_existing: RESHAPER_CALIBRATE
gcode:
    RESHAPER_CALIBRATE FREQ_START=20 FREQ_END=150
    
[gcode_macro PRINT_END]
gcode:
    SET_IDLE_TIMEOUT TIMEOUT={printer.configfile.settings.idle_timeout.timeout}         ; set timeout back to configured value
    CLEAR_PAUSE
    save_zoffset
    M106 P2 S0
    M106 P0 S0
    M106 P3 S0
    
    M104 S0
    M140 S0
    M141 S0

    M220 S100
    M221 S100
    SET_STEPPER_ENABLE STEPPER=stepper_x enable=0
	SET_STEPPER_ENABLE STEPPER=stepper_y enable=0
	SET_STEPPER_ENABLE STEPPER=stepper_z enable=1
    SET_STEPPER_ENABLE STEPPER=stepper_z1 enable=1
	SET_STEPPER_ENABLE STEPPER=extruder enable=0
	
    DISABLE_ALL_SENSOR
    SET_GCODE_OFFSET Z=0 MOVE=0
    BED_MESH_CLEAR
    G31
    CLEAR_LAST_FILE
    BEEP I=2 DUR=500
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

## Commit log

2024-04-15 new nozzle clean, and other config changes
    [gcode_macro.cfg]
2024-04-15 config changes
    [printer.cfg]
2024-04-15 changed folders
    [Bed Build Plate Alignment Stops v1 (Qidi Slicer).3mf, Bed Build Plate Alignment Stops v1.f3d, Bed Build Plate Alignment Stops v1.stl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]
2024-04-16 fix variable error, raise fan thres
    [gcode_macro.cfg, printer.cfg]
2024-04-16 fix params error
    [gcode_macro.cfg]
2024-04-16 update changes
    [gcode_macro.cfg, printer.cfg]
2024-04-16 Upload stock klippy
    [display.cfg, menu.cfg, temperature_sensors.cfg]
2024-04-16 added documentation
    [gcode_macro.cfg]
2024-04-16 Fix output for display
    [gcode_macro.cfg]
2024-04-16 version 2 plate guide
    [Bed Build Plate Alignment Stops v2.stl, makerworld.3mf]
2024-04-16 added cad
    [Bed Build Plate Alignment Stops v1.step, Bed Build Plate Alignment Stops v2.f3d, Bed Build Plate Alignment Stops v2.step]
2024-04-18 Undo felt wipe changes
    [Bed Build Plate Alignment Stops v1 (Qidi Slicer).3mf, Ugly Spool Holder (Qidi Slicer).3mf, Ugly Spool Holder.3mf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]
2024-04-19 Added 256mm plate guide
    [Bed Build Plate Alignment Stops v1 [Bambu 256].stl, Bed Build Plate Alignment Stops v2 [Bambu 256].stl, makerworld [v1 256].3mf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]
2024-04-19 calibrated filament sensor, use PID for host fan
    [printer.cfg]
2024-04-21 adaptive bangbang control for board fan
    [printer.cfg]
2024-04-21 added dump vars by ellis
    [gcode_macro.cfg]
2024-07-08 updated to v4.4.21
    [gcode_macro.stock.4.4.21.cfg, printer.stock.4.4.21.cfg]
2024-07-09 fix errors
    [gcode_macro.cfg, printer.cfg]
2024-07-09 more squish
    [gcode_macro.cfg]
2024-07-23 updated z offset code
    [gcode_macro.cfg, printer.cfg]
2024-07-23 revamped z offset
    [gcode_macro.cfg, printer.cfg]
2024-07-23 added skew correction
    [printer.cfg]
2024-08-05 fix tmc temperature None when not homed
    [printer.cfg]
